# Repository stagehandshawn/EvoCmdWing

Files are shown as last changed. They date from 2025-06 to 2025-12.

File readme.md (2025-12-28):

# EvoCmdWing - [Wiki](https://github.com/stagehandshawn/EvoCmdWing/wiki)

<table width="100%">
  <tr>
    <td width="70%">
      <table width="100%">
        <tr>
          <td align="left">
            <strong>Author:</strong> ShawnR
          </td>
          <td align="right">
            <strong>Contact:</strong> <a href="mailto:stagehandshawn@gmail.com">stagehandshawn@gmail.com</a>
          </td>
        </tr>
      </table>
      <br>
      Control grandMA3 onPC with a custom keyboard with 5 attribute encoders and 8 XKey encoders synced using Midi, backlit Xkeys with on/off and color status (follows appearances).
      <br><br><blockquote>
        <strong>Note:</strong> This Guide is a work in progress but EvocmdWing is fully functional. I continue to work on the repo as time permits.
      </blockquote>
    </td>
    <td width="30%" align="right" valign="top">
      cmdwing
    </td>
  </tr>
</table>

---
## Project Images

<table>
  <tr>
    <td width="50%">
      cmdwingtop
    </td>
    <td width="50%">
      cmdwingside
    </td>
  </tr>
  <tr>
    <td width="50%">
      cmdwingback
    </td>
    <td width="50%">
      faderwingcmdwing
    </td>
  </tr>
</table>

**Watch the demo video**

Watch the demo video (https://www.youtube.com/watch?v=7ICJlkqCzxY)

## Overview
 - Sends custom keys to grandMA3 onPC when paired with `/help_files/EvoCmdWingv0.2_keyboard_shortcuts.xml` you will have a nice control surface.
 - LED feedback for XKeys with manual brightness adjustment  
   - Hold "Encoder Flip" button and Rotate Encoder 11 (logo), 12 (Sequence Off brightness), 13(Sequence On brightness)
 - 5 Relative Attribute Encoders
   - Sensitivity adjustment - Hold "Encoder Flip" button and adjust using Encoder 5 - XKeys will show level (1-8)
 - 8 Absolute XKey Encoders
   - Sensitivity adjustment - Hold "Encoder Flip" button and adjust using Encoder 6 - XKeys will show level (1-8)
 - Keyboard now uses custom keyboard firmware (better enumeration than QMK) [EvoCmdWingKeyboard](https://github.com/stagehandshawn/EvoCmdWingKeyboard) You can find the compiled firmware here
 - Designed with
   - D-Type panel mount openings for changes/additions later without reprinting (e.g., adding Art-net to DMX module, hardware midi, or LTC generator)
   - Extra stand-offs for adding prototype boards for extra design options

## Getting started
- [Bill Of Materials](https://github.com/stagehandshawn/EvoCmdWing/wiki/Bill-of-Materials)

- [Pin Assignments](https://github.com/stagehandshawn/EvoCmdWing/wiki/Pin-Assignments)

- [Wiring Diagrams](https://github.com/stagehandshawn/EvoCmdWing/wiki/Wiring-Diagrams)

## Required firmware for keyboard
- There is now a folder `./keyboard_custom_firmware` that has custom keyboard firmware for the keyboard
- I have left the QMK firmware but the custom keyboard works better with windows as I had some trouble with disconneting and reconneting the EvoCmdWing requiring a reboot for the keyboard to enumerate.
- You can also find the repo with the code to the custom keyboard here [EvoCmdWingKeyboard](https://github.com/stagehandshawn/EvoCmdWingKeyboard)

## Required Plugins
#### EvoCmdWingMidi

- Lua script `/lua/evocmdwingmidi_main.lua`
- Polls executors and sends fader value, on/on status, and color updates to EvoCmdWing using midi.  
- Tracks sequences set to the XKeys and keeps them synced between page changes and sequence moves.  
- You can set custom Encoder Press actions (toggle is default) in Midi Remotes for more control.  

  - The plugin will create required Midi Remotes automatically if they are not present.  
  - You can create them manually with the plugin and batch change the action for pressing the encoder.  
  - You can change each one seperatly in the Midi Remtoes option as well.  

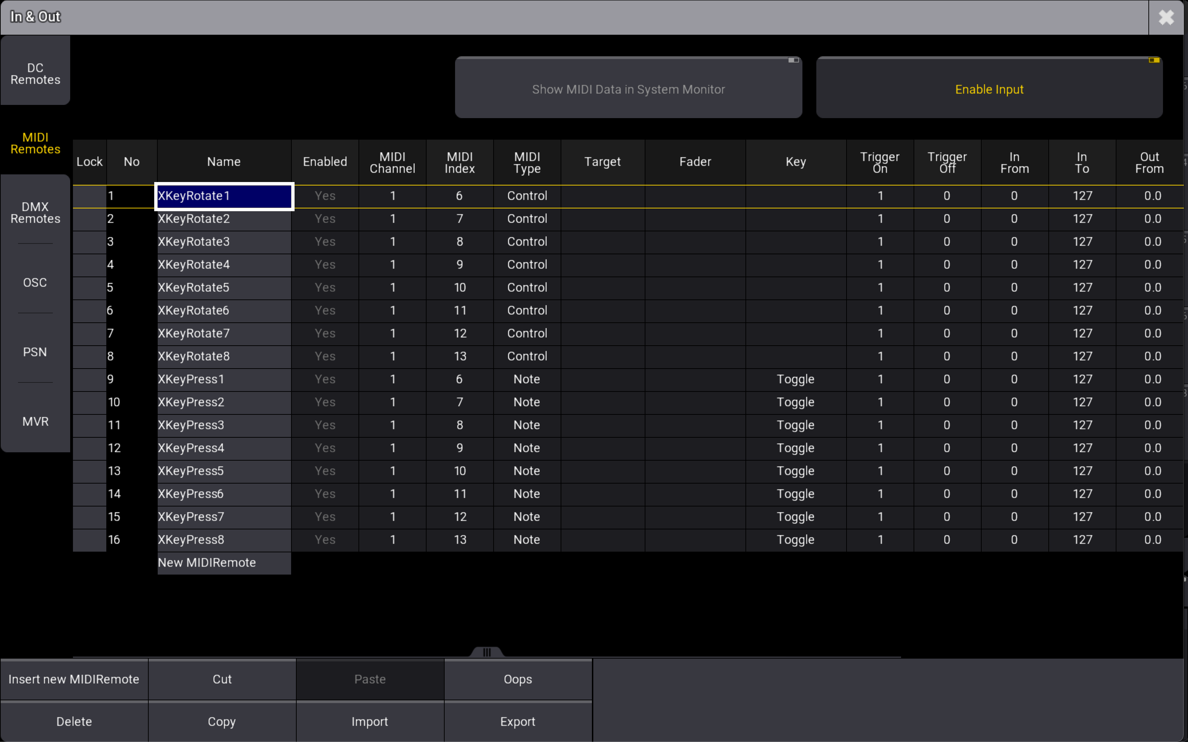
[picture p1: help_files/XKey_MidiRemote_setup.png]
midiRemotes


#### [Pro Plugins MidiEncoders](https://www.ma3-pro-plugins.com/midi-encoders)  
 - Required for taking Midi input and controlling the attribute encoders.  
 - Use Midi Standard and Relative Mode 3.  
 - The top backlit button refered to as "Encoder Flip" is used to flip from Inner/Outter encoder usage, USE NOTE 14.

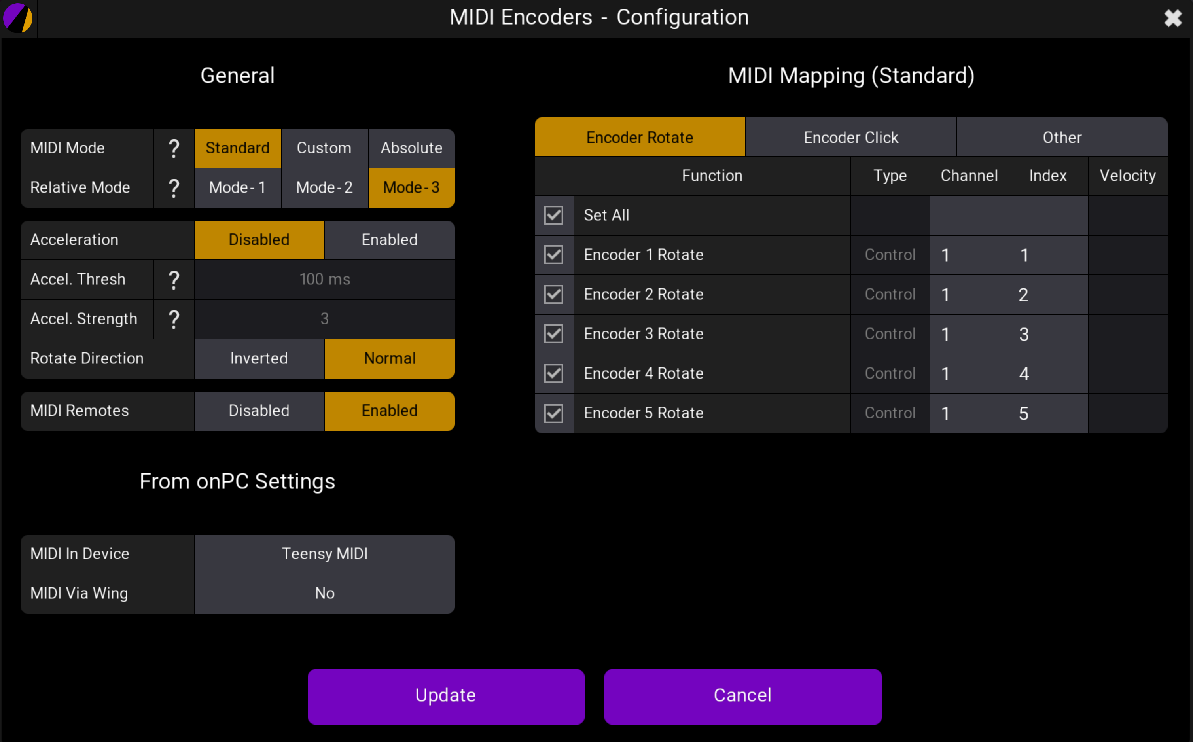
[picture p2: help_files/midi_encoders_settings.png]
midi_encoders_settings


## Full Instructions comming soon, for now...
 - Check the [Wiki](https://github.com/stagehandshawn/EvoCmdWing/wiki)  
 - The `/help_files` and `/images` folders have some helpful files.  

## Inspiration
 - Check out this project! I used it as a starting point but eventually redesigned it to be closer to the layout of a console and to have more control surfaces, and feedback.
 - https://www.thingiverse.com/thing:6464653
 - Thanks to Nathan_I3 for the inspiration for this project!

## Also check out [EvoFaderWing](https://github.com/stagehandshawn/EvoFaderWing) for a complete at home programming setup.
evocmdfaderwing
#### More to come. Thank you for checking out my project!

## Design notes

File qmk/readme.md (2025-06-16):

# These are the files needed to compile the custom keyboard for the teensy 4.0
# you will need qmk cli, you can use the keymap for a different mcu, the teensy is overkill
# there are many resources on  building custom keyboard that will help with wiring

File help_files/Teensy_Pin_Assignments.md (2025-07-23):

# Teensy 4.1 Pin Assignments - EvoCmdWing

## Overview
The EvoCmdWing uses a Teensy 4.1 mcu to manage 13 encoders with buttons, Inner/outter toggle, NeoPixel LEDs, and MIDI communication for the grandMA3.

## Encoder Pin Assignments

### Attribute Encoders (1-5)

| Encoder | Pin A | Pin B | Button Pin | MIDI Note | Function |
|---|---|---|---|---|---|
| 1 | 0 | 1 | 28 | 1 | Attribute Control |
| 2 | 2 | 3 | 29 | 2 | Attribute Control |
| 3 | 4 | 5 | 30 | 3 | Attribute Control |
| 4 | 6 | 7 | 31 | 4 | Attribute Control |
| 5 | 8 | 9 | 32 | 5 | Attribute Control |

### XKey Encoders (6-13) 
*Mapped to grandMA3 XKeys 1-8 (Executors 291-298)*

| Encoder | Pin A | Pin B | Button Pin | MIDI Note | XKey # | Executor |
|---|---|---|---|---|---|---|
| 6 | 11 | 12 | 33 | 6 | 1 | 291 |
| 7 | 14 | 15 | 34 | 7 | 2 | 292 |
| 8 | 16 | 17 | 35 | 8 | 3 | 293 |
| 9 | 18 | 19 | 36 | 9 | 4 | 294 |
| 10 | 20 | 21 | 37 | 10 | 5 | 295 |
| 11 | 22 | 23 | 38 | 11 | 6 | 296 |
| 12 | 24 | 25 | 39 | 12 | 7 | 297 |
| 13 | 26 | 27 | 40 | 13 | 8 | 298 |

## Attribute Encoder Inner/Outter Toggle

| Pin | Function | MIDI Note | Description |
|-----|---|---|---|
| 41  | Inner/Outer Toggle | 14 | Switches encoder functions between inner/outer ring |
| 13  | Latch LED || Status LED for Inner/Outer encoder mode |

**LED Indicator:**
- Pin 13 (Latch LED) shows Inner/Outer mode status
- LED ON = Outer mode active
- LED OFF = Inner mode active

## NeoPixel LED Configuration

| Pin | Function | Description |
|-----|---|---|
| 10  | NeoPixel Data | WS2812B LED strip data signal (58 total pixels) |

### Total LED Count: 58 Pixels

| LED Range | Function | Count | Description |
|---|---|---|---|
| 0-5 | Logo | 6 | Project logo illumination |
| 6-57 | XKey LEDs| 52 | Status indicators for XKeys |

### XKey LED Mapping
*Each XKey has 2 status LEDs*

| XKey | First LED | Second LED | Executor Range |
|---|---|---|---|
| 1 | 7 | 8 | 291 |
| 2 | 10 | 11 | 292 |
| 3 | 13 | 14 | 293 |
| 4 | 16 | 17 | 294 |
| 5 | 20 | 21 | 295 |
| 6 | 23 | 24 | 296 |
| 7 | 26 | 27 | 297 |
| 8 | 29 | 30 | 298 |
| 9 | 32 | 33 | 191 |
| 10 | 35 | 36 | 192 |
| 11 | 38 | 39 | 193 |
| 12 | 41 | 42 | 194 |
| 13 | 45 | 46 | 195 |
| 14 | 48 | 49 | 196 |
| 15 | 51 | 52 | 197 |
| 16 | 54 | 55 | 198 |

**Note:** Pixels 9, 12, 15, 18, 19, 22, 25, 28, 31, 34, 37, 40, 43, 44, 47, 50, 53, 56 are used as spacers/gaps between XKey groups.

## MIDI Configuration

| Channel | Direction | Purpose | CC/Note Range |
|---|---|---|---|
| 1 | Output | Encoder values and button presses | CC 6-13, Notes 1-14 |
| 2 | Input | XKey status and RGB data | CC 1-64 |
| 3 | Input | Page change notifications | CC 1 |

### MIDI Mapping Details

**Outgoing (Channel 1):**
- Encoders 6-13: Send CC 6-13 (fader values)
- All buttons: Send Note On/Off 1-14

**Incoming (Channel 2):**
- XKey Status: CC 1-16 (0=empty, 65=off, 127=on)
- XKey RGB: CC 17-64 (3 CCs per XKey for R,G,B values)

**Incoming (Channel 3):**
- Page Changes: CC 1 (page number 1-127)

## Special Modes

### Brightness Adjustment Mode
**Activation:** Hold button 14 (pin 41)

| Encoder | Function | Range |
|---|---|---|
| 12 | Off-state brightness | 0-255 |
| 13 | On-state brightness | 0-255 |

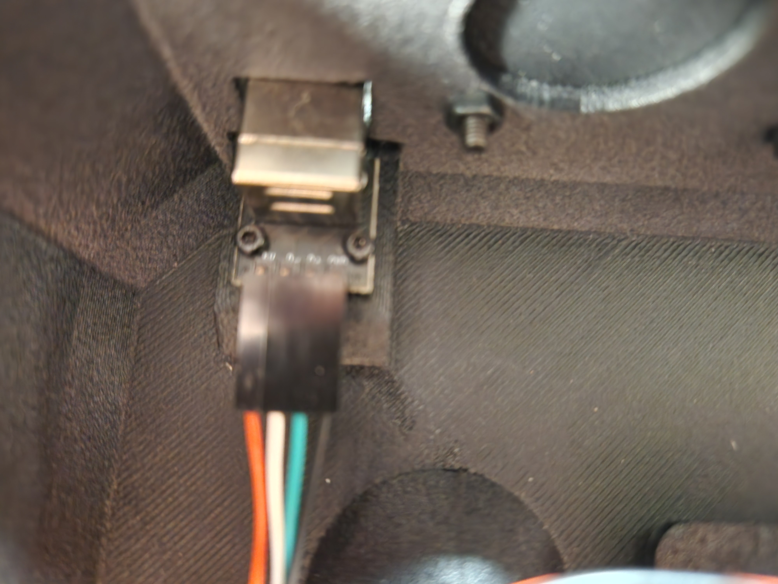
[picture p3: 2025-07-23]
images/usb_b_connector.jpg

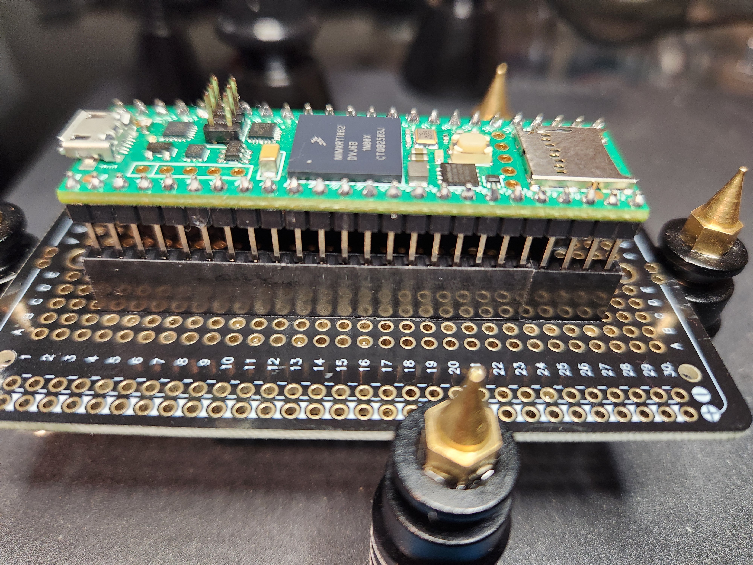
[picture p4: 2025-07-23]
images/teensy_4.1_board_0.jpg

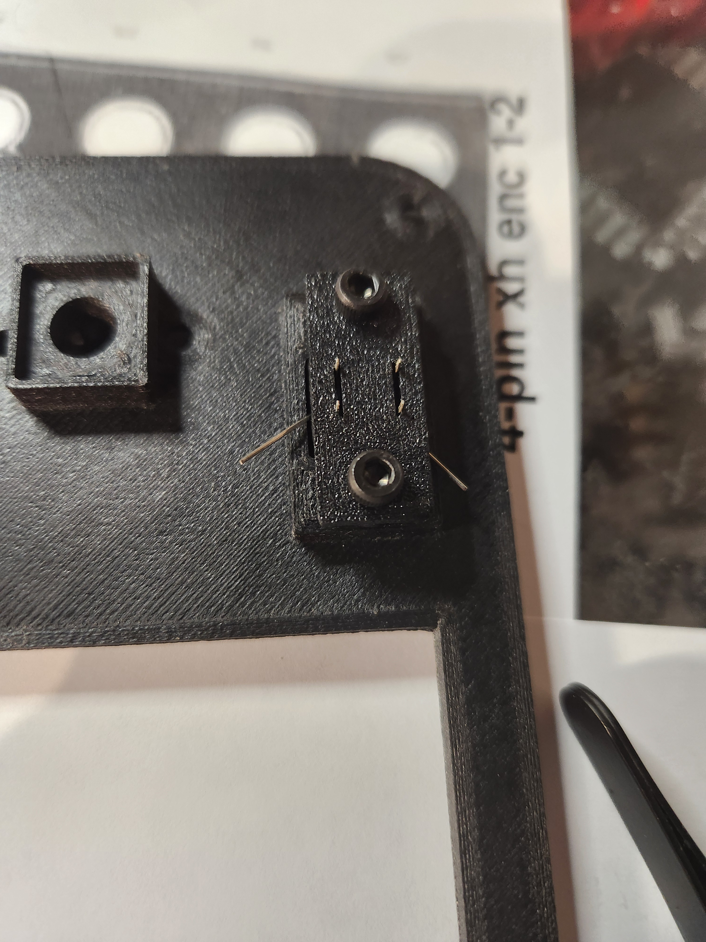
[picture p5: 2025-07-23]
images/encoder_flip_button_bottom.jpg

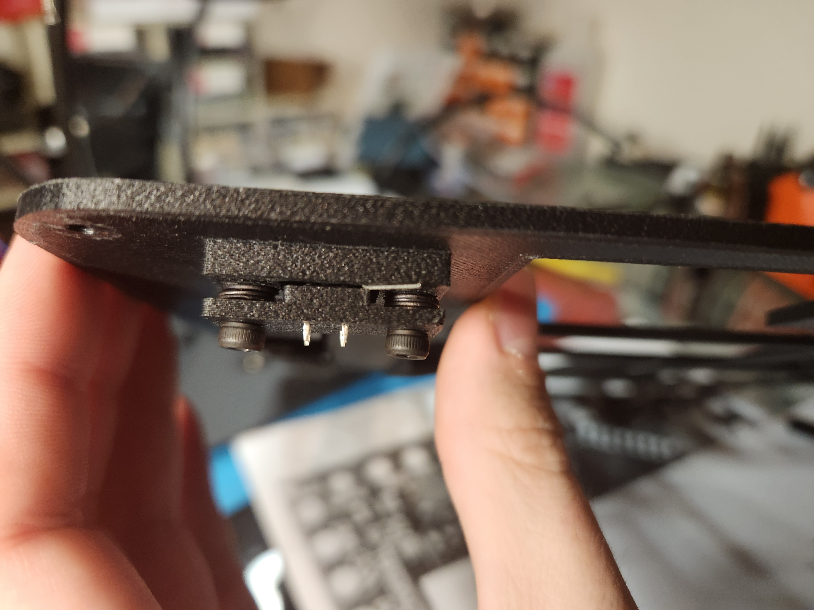
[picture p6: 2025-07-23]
images/encoder_flip_button_side.jpg

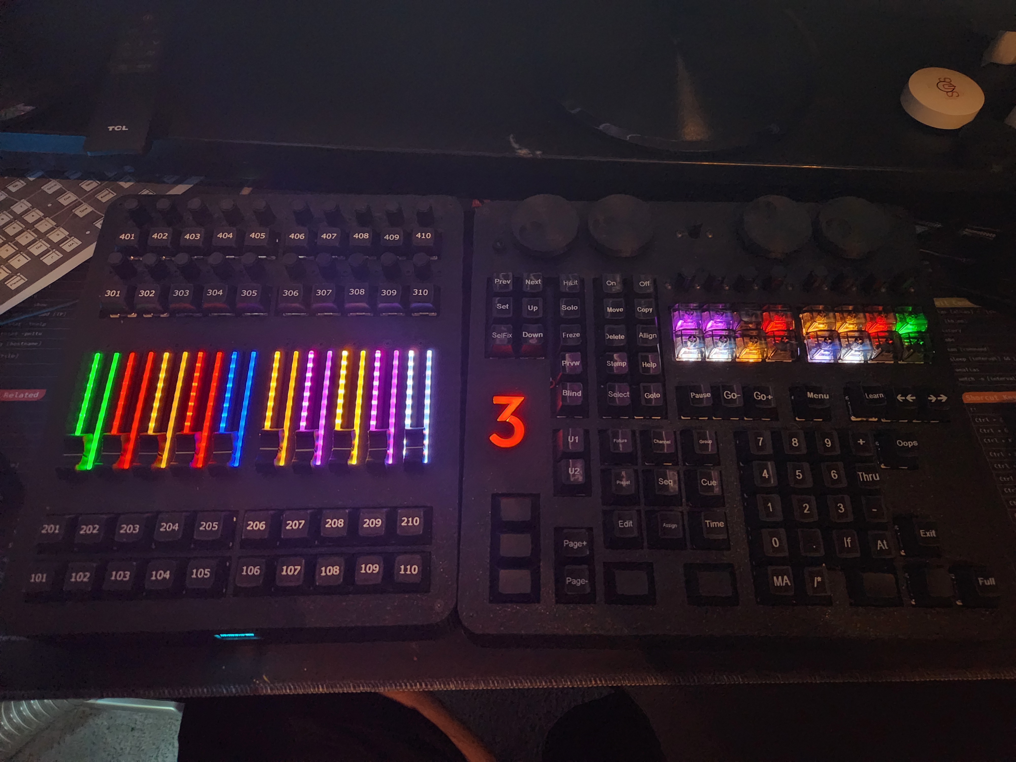
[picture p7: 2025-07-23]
images/evocmdwingv0.2.jpeg

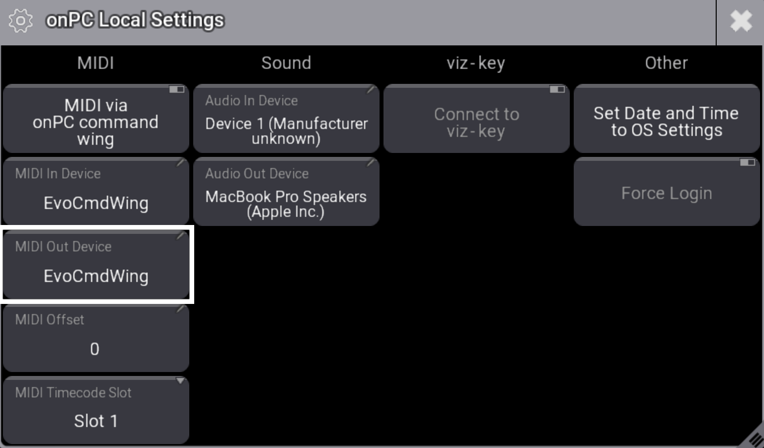
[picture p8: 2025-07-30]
help_files/onPC_midi_settings.png

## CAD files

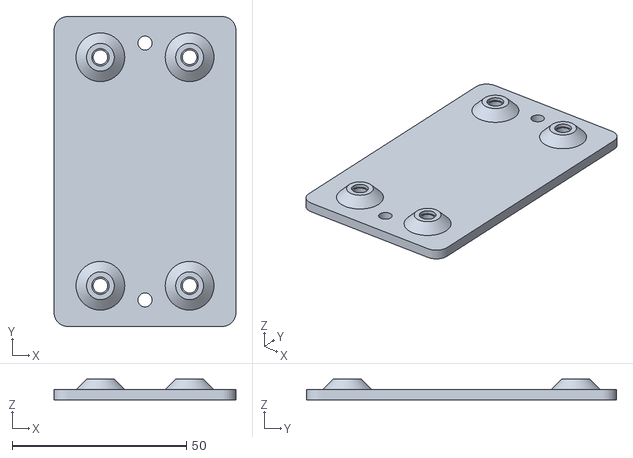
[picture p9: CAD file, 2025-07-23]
Cad_models/V0.2/stls/board_mounts/70X30mm_board_mount.stl
52.2 x 89.0 x 6.00

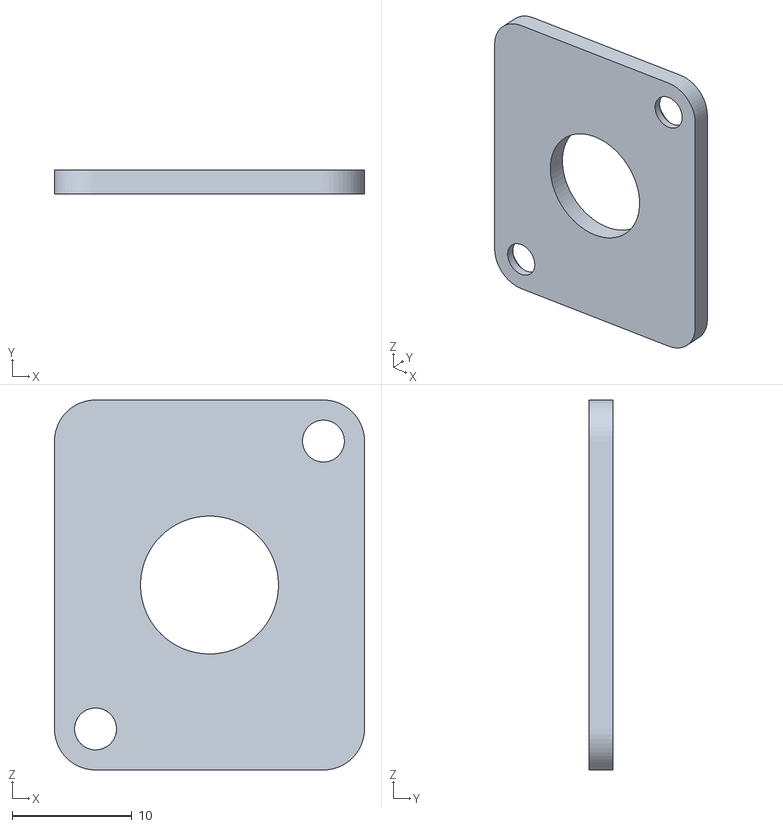
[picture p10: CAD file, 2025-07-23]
Cad_models/V0.2/stls/D-type_DC_barrel_plate.stl
25.8 x 2.00 x 30.8

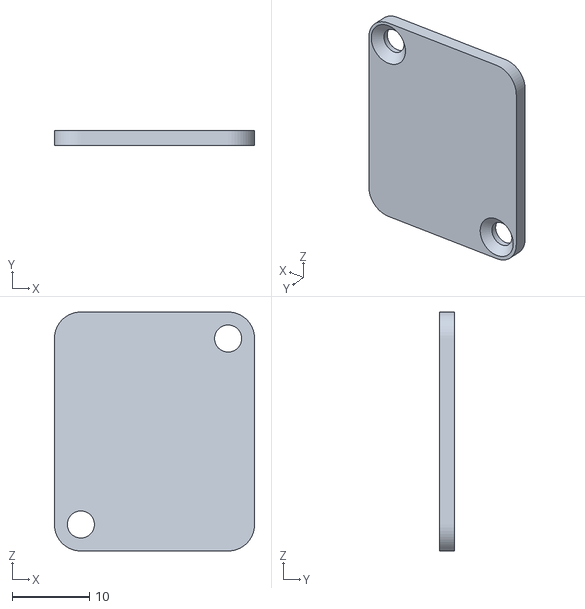
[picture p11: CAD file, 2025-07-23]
Cad_models/V0.2/stls/Blank D-type.stl
25.8 x 2.00 x 30.8

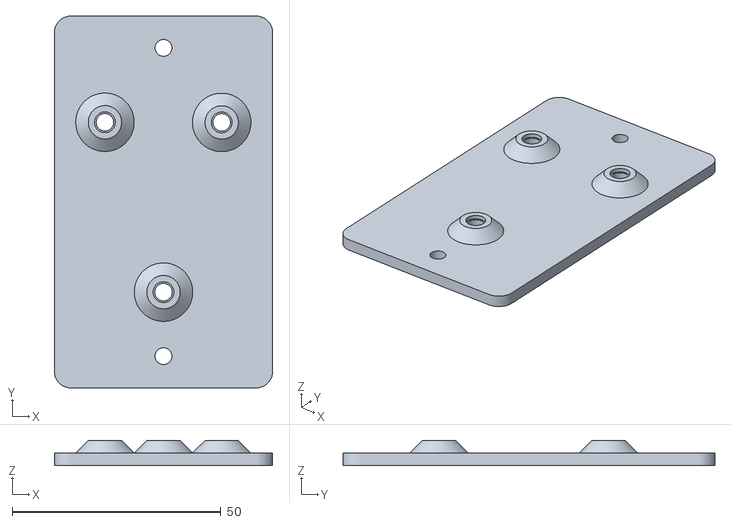
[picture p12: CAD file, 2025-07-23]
Cad_models/V0.2/stls/board_mounts/teensy4.0_breakout_mount.stl
52.2 x 89.0 x 6.00

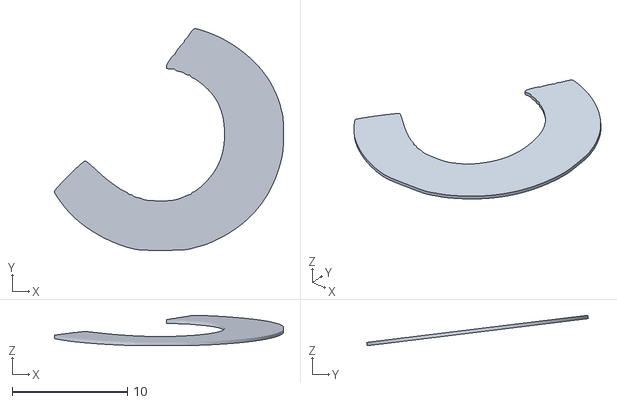
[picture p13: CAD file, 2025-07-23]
Cad_models/V0.2/stls/Logo_3_bottom.stl
19.9 x 19.2 x 2.64

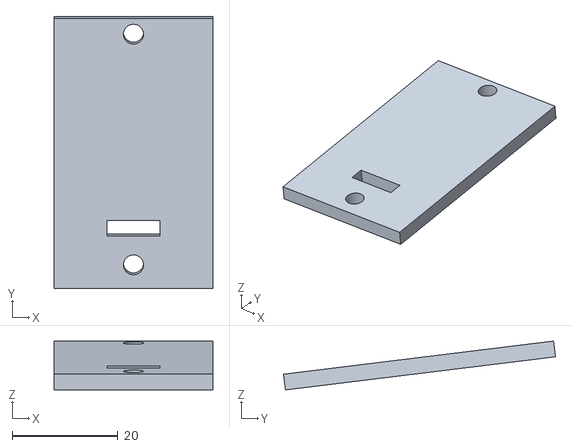
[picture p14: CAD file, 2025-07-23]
Cad_models/V0.2/stls/logo_led_holder.stl
30.0 x 51.5 x 9.25

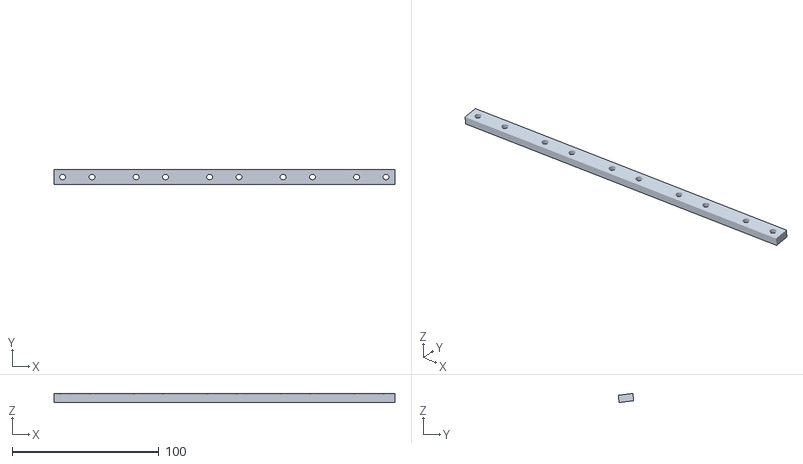
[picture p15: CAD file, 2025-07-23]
Cad_models/V0.2/stls/big encoder mount.stl
232.0 x 10.5 x 6.18

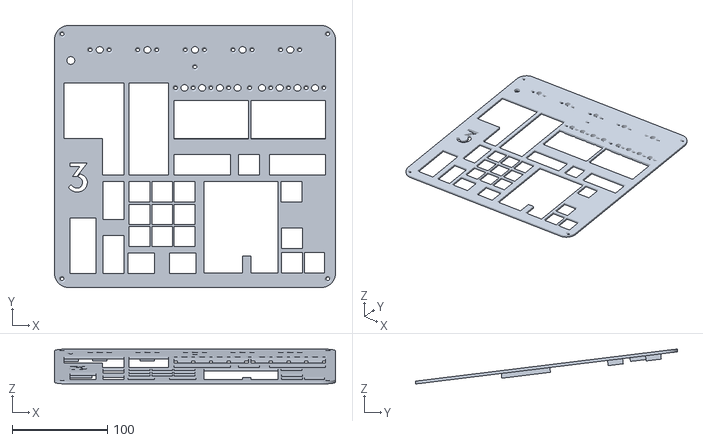
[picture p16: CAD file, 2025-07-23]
Cad_models/V0.2/stls/Top.stl
295.0 x 275.3 x 36.7

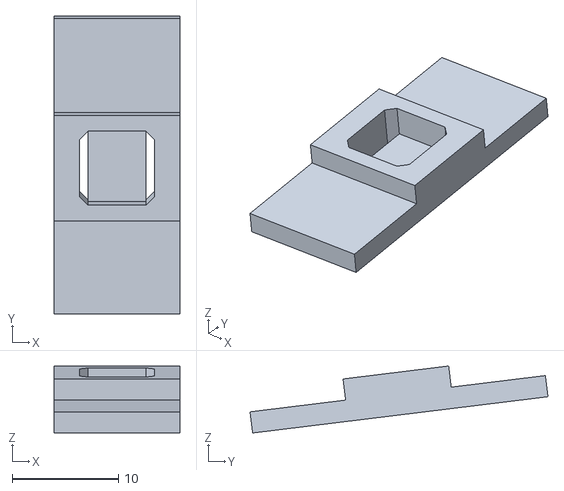
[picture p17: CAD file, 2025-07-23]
Cad_models/V0.2/stls/encoder_flip_button_body.stl
11.8 x 28.0 x 6.29

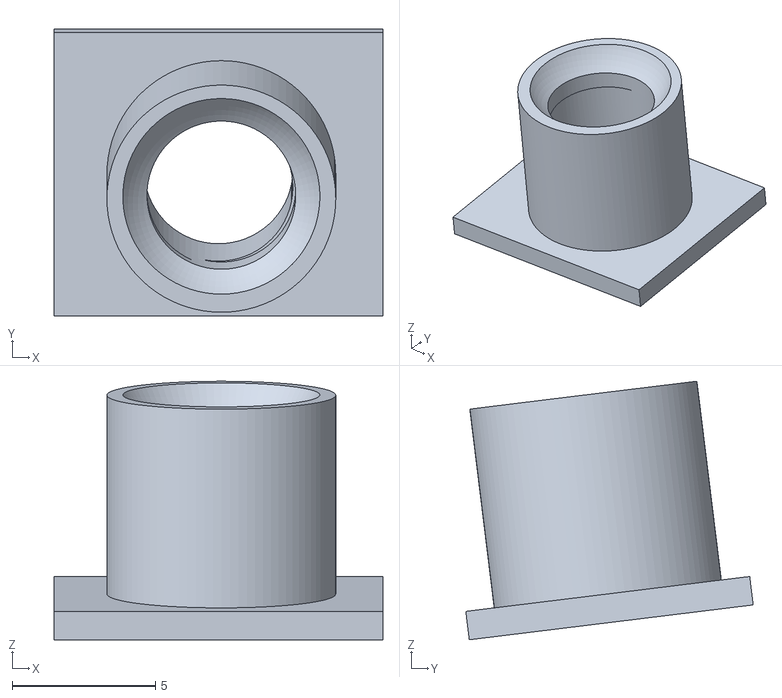
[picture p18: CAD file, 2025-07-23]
Cad_models/V0.2/stls/encoder_flip_button_5mmLED.stl
11.5 x 10.0 x 9.04

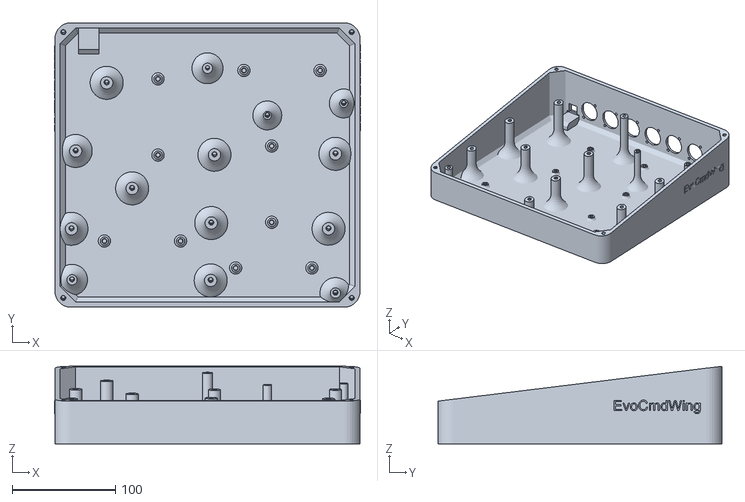
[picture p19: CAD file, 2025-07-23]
Cad_models/V0.2/stls/Base.stl
296.0 x 275.0 x 75.0

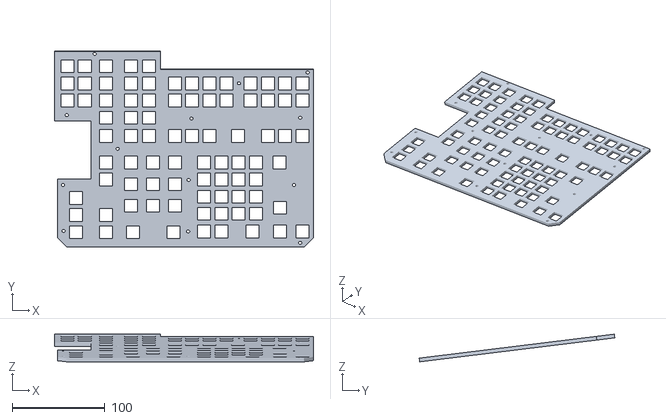
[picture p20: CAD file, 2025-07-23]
Cad_models/V0.2/stls/Keyplate.stl
278.9 x 210.7 x 29.8

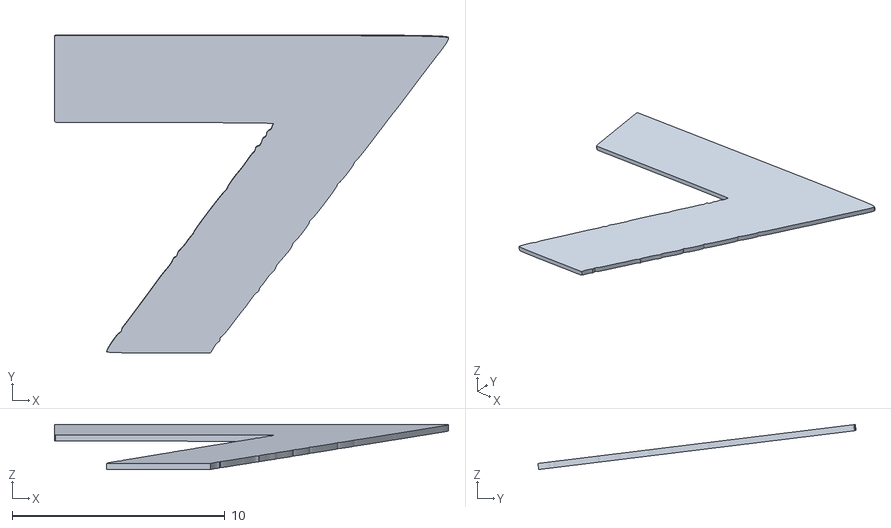
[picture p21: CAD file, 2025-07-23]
Cad_models/V0.2/stls/Logo_3_top.stl
18.5 x 15.0 x 2.12

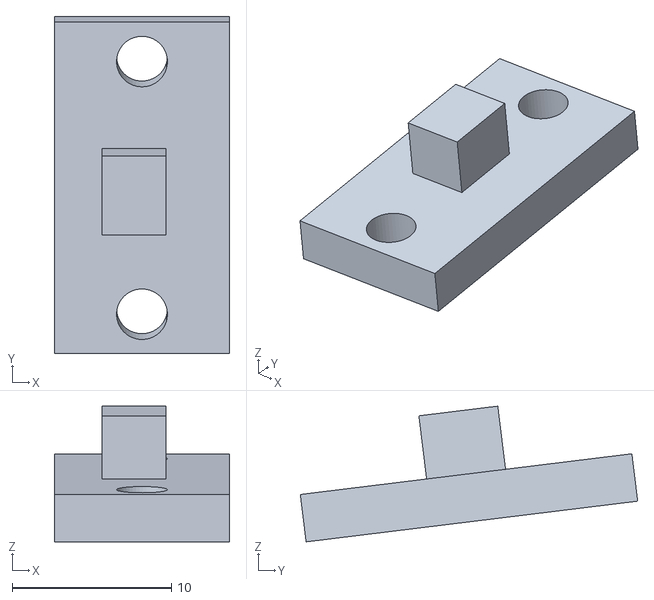
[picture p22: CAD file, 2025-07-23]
Cad_models/V0.2/stls/button_mount.stl
11.0 x 21.2 x 8.53

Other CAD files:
Cad_models/V0.2/stls/small_encoder_mount.stl
Cad_models/V0.2/stls/encoder_flip_button_soild_no_led.stl
Cad_models/V0.2/stls/encoder_wheel.stl
Cad_models/V0.1/stls/Keyplate.stl
Cad_models/V0.1/gma3cmdwingV1.f3d
Cad_models/V0.1/stls/Base.stl
Cad_models/V0.1/stls/Top.stl
Cad_models/V0.1/stls/big encoder mount.stl
Cad_models/V0.1/stls/encoder_spacer.stl
Cad_models/V0.1/stls/encoder_wheel.stl
Cad_models/V0.1/stls/small encoder mount.stl
Cad_models/V0.1/stls/stand_tilted.stl

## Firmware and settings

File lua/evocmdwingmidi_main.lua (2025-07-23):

-- EvoCmdWingMidi v0.2
-- This lua script will poll midi remotes in grandma3 for the name XKeyRotate1-8 and XKeyPress1-8
-- XKeyRotate remotes handle fader control from encoders with MIDI feedback of current fader value
-- XKeyPress remotes target the same sequences but allow manual key configuration (press for toggle/on/off etc..)

-- MIDI Remotes:
--     Main loop will auto create the following MIDI Remotes when not present
--         XKeyRotate1-8: channel 1 cc 6-13 (fader control with feedback)
--         XKeyPress1-8: channel 1 note 6-13 (key presses, manual configuration)
--    The defualt function of pressing an Encoder (XKeyPress1-8) is Toggle, you can manually change each or use the Create Midi Remotes button to batch change them

-- The script will:
--     Update the MidiRemote Targets with the current sequences assigned to the XKeys to keep track of pages changes and moving of sequences
--     Track and send the fader values for Executors 291-298 for syncing encoder values for XKeys 1-8
--     Track and send the status of Executors 191-198 and 291-298 (XKeys 1-16) Tracks: Populated/On/Off/Appearance Color
--     Cache status data to reduce midi traffic on page changes and will send updates when assignments or appearance changes

-- Midi Channels:
--     Channel 1: Fader sync: XKeys 1-8 use CC 6-13 (only on sequence changes/page changes) Manually chaning XKey Encoder values in software will cause Physical Encoders to be out of sync until page/sequence change
--     Channel 2: Status: XKeys 1-16 use CC 1-16 (populated/on/off state)
--     Channel 2: RGB: XKeys 1-16 use CC 17-64 (3 CCs each (rgb), only sent when populated and not black)
--     Channel 3: Page changes: CC 1 = current page number (1-127)

-- Status encoding:
--     Status encoding: 0=not populated, 65=populated+off, 127=populated+on
--     RGB: 0-127 per rgb channel, black sequences sent as white (127,127,127) for visibility
--         You can change the default color variables to replace black appearances
--     Page tracking: Caches state for pages, only sends changes
--     Fader sync: Only sends fader values when sequence assignments change (prevents encoder jumping)

-- XKey RGB
--     You can change the defualt color of newly created XKeys below, it replaces black (can be black for default LEDs off)

-- Many thanks to LenschCode for the original code from Midi Executors v1.1.0
-- GNU GPLv3

local loop
-- Refreshrate in seconds, I spent a lot of time getting the script to be as effecient as possible beause we are using polling, 100ms seems to work great
local rate = 0.1         --100ms

-- Starting CC for MIDI feedback
local startingCC = 6
-- local endingCC = startingCC + 7  -- CC 6-13 for XKeys 1-8
local midiChannel = 1
local statusMidiChannel = 2
local pageMidiChannel = 3

-- Default color for black (0,0,0) sequences - for visibility
local defaultRed = 255
local defaultGreen = 255
local defaultBlue = 255

local running = false
local debugMode = false -- Debug output mode - off by default
local currentPage = nil -- Track current page

-- Page-based state tracking for up to 127 pages
local pageIndex = {} -- Track which pages we've indexed: pageIndex[pageNum] = true
local pageExecutorStates = {} -- [pageNum][execNum] = {populated, on, colorR, colorG, colorB}
local startupComplete = false -- Track if we've done initial indexing

-- Change tracking for exeecutors
local changedExecutors = {} -- List of executors that changed on current page

-- MIDI Remote caching
local cachedXKeyRemotes = {} -- Cache of found XKey remotes: {remote_object, exec_info}
local remoteCacheComplete = false -- Track if we've cached all remotes
local expectedRemoteCount = 16 -- XKeyRotate1-8 + XKeyPress1-8

-- All Executors (Xkeys) to monitor
local EXECUTORS_TO_MONITOR = {191,192,193,194,195,196,197,198,291,292,293,294,295,296,297,298}

-- Current page
local currentCyclePageNum = nil

-- Debug print function - only prints if debug mode is enabled
local function DebugPrint(...)
    if debugMode then
        Printf(...)
    end
end


-- Clear all cached state variables (called on script startup)
local function clearAllCachedState()
    currentPage = nil
    pageIndex = {}
    pageExecutorStates = {}
    startupComplete = false
    changedExecutors = {}
    
    -- Clear MIDI remote cache
    cachedXKeyRemotes = {}
    remoteCacheComplete = false
    
    -- Clear page cache
    currentCyclePageNum = nil
    
    DebugPrint("Cached state cleared - ready for direct access sync")
end


local function getDirectExecutorInfo(execNum)
    -- Get executor status
    local exec, page = GetExecutor(execNum)
    
    if not exec then
        -- Executor doesn't exist
        return {
            faderValue = 0,
            isOn = false,
            isPopulated = false,
            color = {r = 0, g = 0, b = 0},
            object = nil,
            faderRef = nil
        }
    end
    
    -- Get all live values directly from the executor
    local faderValue = exec:GetFader{token = "FaderMaster", faderDisabled = false} or 0
    local myObject = exec.Object
    local isPopulated = (myObject ~= nil)
    local isOn = isPopulated and myObject:HasActivePlayback() or false
    
    -- Get color data
    local color = {r = 0, g = 0, b = 0}
    if isPopulated then
        local apper = myObject["APPEARANCE"]
        if apper then
            color = {
                r = apper['BACKR'] or 0,
                g = apper['BACKG'] or 0,
                b = apper['BACKB'] or 0
            }
        end
    end
    
    -- Get fader reference for MIDI remote assignment
    local faderRef = nil
    local objectListExec = ObjectList("page " .. currentCyclePageNum .. "." .. execNum)[1]
    if objectListExec then
        faderRef = objectListExec.fader
    end
    
    return {
        faderValue = faderValue,
        isOn = isOn,
        isPopulated = isPopulated,
        color = color,
        object = myObject,
        faderRef = faderRef
    }
end


local function getXKeyMapping(remoteName)
    -- Handle both XKeyRotate and XKeyPress remotes
    local rotateNum = remoteName:match("^[Xx][Kk]ey[Rr]otate(%d+)$")
    local pressNum = remoteName:match("^[Xx][Kk]ey[Pp]ress(%d+)$")
    
    local executorNumber = nil
    local remoteType = nil
    
    local keyNum = nil
    if rotateNum then
        keyNum = tonumber(rotateNum)
        executorNumber = 290 + keyNum -- XKeyRotate1 = 291, etc.
        remoteType = "Fader"
    elseif pressNum then
        keyNum = tonumber(pressNum)
        executorNumber = 290 + keyNum -- XKeyPress1 = 291, etc.
        remoteType = "Key"
    end
    
    if executorNumber and (executorNumber >= 291 and executorNumber <= 298) then
        return {
            page = currentCyclePageNum,
            id = executorNumber,
            type = remoteType,
            xkeyNum = keyNum
        }
    else
        return nil
    end
end


local function sendMidiFeedback(ccNumber, value)
    local midiValue = math.floor((value / 100) * 127)
    local command = 'SendMIDI "Control" ' .. midiChannel .. '/' .. ccNumber .. ' ' .. midiValue
    Cmd(command)
    
    coroutine.yield(0.010) -- 10ms delay between midi sends  to not overwhelm teensy buffer
end


local function sendMidiStatus(channel, ccNumber, value)
    local midiValue = value > 127 and 127 or (value < 0 and 0 or math.floor(value))
    local command = 'SendMIDI "Control" ' .. channel .. '/' .. ccNumber .. ' ' .. midiValue
    Cmd(command)
    coroutine.yield(0.010) -- 10ms delay
end

local function sendPageChange(pageNumber)
    local pageValue = pageNumber > 127 and 127 or (pageNumber < 1 and 1 or math.floor(pageNumber))
    sendMidiStatus(pageMidiChannel, 1, pageValue)
    DebugPrint("Page change sent: %d", pageValue)
end


local function sendMidiColor(channel, ccBase, color)
    -- Convert 0-255 color values to 0-127 MIDI values
    local rMidi, gMidi, bMidi
    
    if color.r == 0 and color.g == 0 and color.b == 0 then
        -- If color is black (0,0,0), use default color for visibility
        rMidi = math.floor((defaultRed / 255) * 127)
        gMidi = math.floor((defaultGreen / 255) * 127)
        bMidi = math.floor((defaultBlue / 255) * 127)
    else
        rMidi = math.floor((color.r / 255) * 127)
        gMidi = math.floor((color.g / 255) * 127)
        bMidi = math.floor((color.b / 255) * 127)
    end
    
    sendMidiStatus(channel, ccBase, rMidi)     -- Red
    sendMidiStatus(channel, ccBase + 1, gMidi) -- Green
    sendMidiStatus(channel, ccBase + 2, bMidi) -- Blue
end

-- Get cached executor state for comparison
local function getCachedExecutorState(pageNum, execNum)
    if not pageExecutorStates[pageNum] then
        return nil, nil, nil, nil, nil -- No cached data for this page
    end
    
    local cached = pageExecutorStates[pageNum][execNum]
    if not cached then
        return nil, nil, nil, nil, nil -- No cached data for this executor
    end
    
    return cached.populated, cached.on, cached.colorR, cached.colorG, cached.colorB
end

-- Cache executor state for future comparison
local function setCachedExecutorState(pageNum, execNum, populated, on, colorR, colorG, colorB)
    if not pageExecutorStates[pageNum] then
        pageExecutorStates[pageNum] = {}
    end
    
    pageExecutorStates[pageNum][execNum] = {
        populated = populated,
        on = on,
        colorR = colorR,
        colorG = colorG,
        colorB = colorB,
    }
end

-- Send fader sync for a specific executor (only when sequence assignment changes)
local function sendFaderSync(execNum, xkeyNum, reason)
    local currentPageNum = currentCyclePageNum
    
    -- Only send fader sync for executors 291-298 (XKeys 1-8) (Encoders 6-13)
    if execNum < 291 or execNum > 298 then
        return false
    end
    
    
    -- Get current fader value to sync Teensy encoder tracking
    local currentValue = getDirectExecutorInfo(execNum).faderValue
    local faderCCNumber = startingCC + xkeyNum - 1
    sendMidiFeedback(faderCCNumber, currentValue)
    
    DebugPrint("Executor %d (XKey %d): Fader sync=%d%% (CC:%d) - %s", 
           execNum, xkeyNum, math.floor(currentValue), faderCCNumber, reason)
    
    -- Preserve cached state (no fader state tracking needed)
    local cachedPopulated, cachedOn, cachedColorR, cachedColorG, cachedColorB = getCachedExecutorState(currentPageNum, execNum)
    setCachedExecutorState(currentPageNum, execNum, cachedPopulated, cachedOn, cachedColorR, cachedColorG, cachedColorB)
    
    return true
end

-- Send MIDI status for a specific executor 
local function sendExecutorStatus(execNum, xkeyNum, force)
    local currentPageNum = currentCyclePageNum
    
    -- Get current states
    local execInfo = getDirectExecutorInfo(execNum)
    local isPopulated = execInfo.isPopulated
    local isOn = execInfo.isOn  
    local color = execInfo.color
    
    local populatedState = isPopulated
    local onState = isOn
    local colorR, colorG, colorB = color.r, color.g, color.b
    
    -- Get cached state for comparison
    local cachedPopulated, cachedOn, cachedColorR, cachedColorG, cachedColorB = getCachedExecutorState(currentPageNum, execNum)
    
    local messagesSent = 0
    local statusChanged = force or (cachedPopulated ~= populatedState) or (cachedOn ~= onState)
    local colorChanged = force or (cachedColorR ~= colorR) or (cachedColorG ~= colorG) or (cachedColorB ~= colorB)
    local sequenceChanged = false
    
    -- Check if sequence assignment changed (for fader sync)
    local wasPopulated = cachedPopulated or false
    local becamePopulated = false
    if statusChanged and execNum >= 291 and execNum <= 298 then
        -- For executors 291-298, check if the populated state changed (sequence assignment)
        if wasPopulated ~= populatedState then
            sequenceChanged = true
            if not wasPopulated and populatedState then
                becamePopulated = true
            end
        end
    else
        -- For executors 191-198 (XKeys 9-16), check if became populated (hard-coded, no MIDI remote management)
        if not wasPopulated and populatedState then
            becamePopulated = true
        end
    end
    
    -- Send status CC only if status changed
    if statusChanged then
        local statusValue = 0
        if isPopulated then
            if isOn then
                statusValue = 127  -- Populated and on
            else
                statusValue = 65   -- Populated and off
            end
        else
            statusValue = 0  -- Not populated
        end
        
        sendMidiStatus(statusMidiChannel, xkeyNum, statusValue)
        messagesSent = messagesSent + 1
        
        DebugPrint("Executor %d (XKey %d): Status=%d (Pop=%s On=%s)", 
               execNum, xkeyNum, statusValue,
               isPopulated and "YES" or "NO", isOn and "YES" or "NO")
        
        -- Send fader sync if sequence assignment changed
        if sequenceChanged then
            sendFaderSync(execNum, xkeyNum, "sequence assignment changed")
        end
    end
    
    -- Send RGB if Key is populated AND color changed, OR Key just became populated (force RGB send for new sequences)
    if isPopulated and (colorChanged or becamePopulated) then
        local rgbCCBase = 16 + (xkeyNum - 1) * 3 + 1
        sendMidiColor(statusMidiChannel, rgbCCBase, color)
        messagesSent = messagesSent + 3
        
        if becamePopulated then
            DebugPrint("Executor %d (XKey %d): RGB=(%d,%d,%d) - newly populated", 
                   execNum, xkeyNum, color.r, color.g, color.b)
        else
            DebugPrint("Executor %d (XKey %d): RGB=(%d,%d,%d)", 
                   execNum, xkeyNum, color.r, color.g, color.b)
        end
    elseif not isPopulated and colorChanged then
        DebugPrint("Executor %d (XKey %d): Unpopulated (no RGB sent)", execNum, xkeyNum)
    end
    
    -- Update cached state if anything was sent or changed
    if statusChanged or colorChanged then
        setCachedExecutorState(currentPageNum, execNum, populatedState, onState, colorR, colorG, colorB)
    end
    
    return messagesSent > 0 -- Indicate if we sent anything
end

-- Send full page data (startup or new page indexing)
local function sendFullPageData(pageNum, reason)
    DebugPrint("=== SENDING FULL PAGE DATA: Page %d (%s) ===", pageNum, reason)
    local messagesSent = 0
    
    -- Send fader sync for executors 291-298 to initialize Teensy encoder tracking
    for execNum = 291, 298 do
        local xkeyNum = execNum - 290  -- 1-8
        if sendFaderSync(execNum, xkeyNum, reason) then
            messagesSent = messagesSent + 1
        end
    end
    
    -- Send status data for all 16
    for _, execNum in ipairs(EXECUTORS_TO_MONITOR) do
        if execNum >= 291 and execNum <= 298 then
            -- Executors 291-298 = XKeys 1-8
            local xkeyNum = execNum - 290
            if sendExecutorStatus(execNum, xkeyNum, true) then
                messagesSent = messagesSent + 1
            end
        elseif execNum >= 191 and execNum <= 198 then
            -- Executors 191-198 = XKeys 9-16  
            local xkeyNum = execNum - 190
            local actualXkeyNum = xkeyNum + 8
            if sendExecutorStatus(execNum, actualXkeyNum, true) then
                messagesSent = messagesSent + 1
            end
        end
    end
    
    -- Mark page as indexed
    pageIndex[pageNum] = true
    
    DebugPrint("Full page data sent: %d messages", messagesSent)
end

-- Send changes for current page
local function sendChangedExecutors()
    local messagesSent = 0
    
    local changedExecCount = 0
    for _ in pairs(changedExecutors) do 
        changedExecCount = changedExecCount + 1 
    end
    
    DebugPrint("=== PROCESSING CHANGES ===\nChanged executors: %d", changedExecCount)
    
    -- Process all changed executors immediately
    for execNum, _ in pairs(changedExecutors) do
        if execNum >= 291 and execNum <= 298 then
            -- Executors 291-298 = XKeys 1-8
            local xkeyNum = execNum - 290  -- 1-8
            
            -- Send status data (includes fader sync if sequence changed)
            if sendExecutorStatus(execNum, xkeyNum, false) then
                messagesSent = messagesSent + 1
                DebugPrint("Executor %d (XKey %d) status updated", execNum, xkeyNum)
            end
            
        elseif execNum >= 191 and execNum <= 198 then
            -- Executors 191-198 = XKeys 9-16
            local xkeyNum = execNum - 190  -- 1-8
            local actualXkeyNum = xkeyNum + 8  -- 9-16
            
            if sendExecutorStatus(execNum, actualXkeyNum, false) then
                messagesSent = messagesSent + 1
                DebugPrint("Executor %d (XKey %d) status updated", execNum, actualXkeyNum)
            end
        end
    end
    
    -- Clear changed executors list after processing
    changedExecutors = {}
    
    DebugPrint("Messages sent: %d", messagesSent)
end

local function checkForExecutorChanges()
    local currentPageNum = currentCyclePageNum
    local contentChanged = false
    local stateChanged = false
    local colorChanged = false
    local pageChanged = false
    
    -- Check if page changed
    if currentPage == nil then
        -- First startup
        currentPage = currentPageNum
        pageChanged = true
        
        if not startupComplete then
            DebugPrint("=== STARTUP: Indexing page %d ===", currentPageNum)
            sendPageChange(currentPageNum)
            sendFullPageData(currentPageNum, "startup")
            startupComplete = true
            return -- Exit early after startup
        end
        
    elseif currentPage ~= currentPageNum then
        -- Page actually changed
        DebugPrint("=== PAGE CHANGE: %d → %d ===", currentPage, currentPageNum)
        currentPage = currentPageNum
        pageChanged = true
        
        -- Send page change notification
        sendPageChange(currentPageNum)
        
        -- Check if this page has been indexed before
        if not pageIndex[currentPageNum] then
            -- New page - send full data including fader sync
            DebugPrint("New page detected - sending full data")
            sendFullPageData(currentPageNum, "new page")
            return -- Exit early after full page send
        else
            -- Known page - send fader sync for encoder tracking, then let normal change detection handle differences
            DebugPrint("Returning to known page %d - sending fader sync", currentPageNum)
            for execNum = 291, 298 do
                local xkeyNum = execNum - 290  -- 1-8
                sendFaderSync(execNum, xkeyNum, "known page change")
            end
        end
    end
    
    -- Check for executor state changes
    for _, execNum in ipairs(EXECUTORS_TO_MONITOR) do

            local execInfo = getDirectExecutorInfo(execNum)
            local currentObject = execInfo.object
            local isPopulated = execInfo.isPopulated
            local currentOnState = execInfo.isOn
            local currentColor = execInfo.color
            
            -- Get cached state for comparison 
            local cachedPopulated, cachedOn, cachedColorR, cachedColorG, cachedColorB = getCachedExecutorState(currentPageNum, execNum)
            
            local executorChanged = false
            
            -- Check if status changed from cached state
            if (cachedPopulated ~= isPopulated) or (cachedOn ~= currentOnState) then
                DebugPrint("[CHANGE] Executor %d: Status changed (Populated: %s, On: %s)", 
                       execNum, isPopulated and "true" or "false", currentOnState and "true" or "false")
                executorChanged = true
                contentChanged = true
                stateChanged = true
            end
            
            -- Check if color changed from cached state
            if (cachedColorR ~= currentColor.r) or (cachedColorG ~= currentColor.g) or (cachedColorB ~= currentColor.b) then
                DebugPrint("[CHANGE] Executor %d: Color changed to RGB(%d,%d,%d)", 
                       execNum, currentColor.r, currentColor.g, currentColor.b)
                executorChanged = true
                colorChanged = true
            end
            
            -- Mark executor as changed if any property changed
            if executorChanged then
                changedExecutors[execNum] = true
            end
    end
    
    -- Send feedback if anything changed (but not for page changes - handled above)
    if not pageChanged and (contentChanged or stateChanged or colorChanged) then
        if contentChanged then
            DebugPrint("=== Executor content changes detected ===")
        end
        if stateChanged then
            DebugPrint("=== Executor state changes detected ===")
        end
        if colorChanged then
            DebugPrint("=== Executor color changes detected ===")
        end
        
        -- Small delay for grandMA to finish processing the changes
        coroutine.yield(0.1) -- 100ms delay
        
        DebugPrint("=== Sending MIDI updates ===")
        sendChangedExecutors()
    end
end


-- MIDI REMOTE CREATION --
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

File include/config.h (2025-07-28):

#ifndef CONFIG_H
#define CONFIG_H

#include <Arduino.h>
#include <Adafruit_NeoPixel.h>
#include <Encoder.h>
#include "eepromStorage.h"

typedef unsigned char byte;

// ================================
// PROJECT INFORMATION
// ================================
const char* const PROJECT_VERSION = "0.2";
const char* const PROJECT_NAME = "EvoCmdWing";

// ================================
// PIN DEFINITIONS
// ================================
const int LED_PIN = 10;              // NeoPixel data pin
const int LATCH_LED_PIN = 13;        // GPIO pin for latching inner outter flip button

// ================================
// ENCODER/BUTTON CONFIGURATION
// ================================
const int N_ENCODERS = 13;
const int N_BUTTONS = 14;

// GPIO pins for encoder a/b
extern const int ENC_PINS[N_ENCODERS][2];

// GPIO pin for encoder click, and inner outter button
extern const int BUTTON_PIN[N_BUTTONS];

// ================================
// MIDI CONFIGURATION
// ================================
// first 5 are for attribute encoders, next 8 are for XKeys encoders
extern const byte ENCODER_NOTES[N_ENCODERS];

// first 5 for encoders, next 8 for XKeys, last one for inner outter flip
extern const byte BUTTON_NOTES[N_BUTTONS];

// Here you can play with the velocity scaling to get the sensitivity you like
// This works well for me with no accel in Pro Plugins Midi Encoders plugin
extern const int VELOCITY_SCALES[8][8];

// Note: Encoder sensitivity variables are now in the config struct (eeprom.h)

//midi channel to send on
extern byte midiCh;

// ================================
// LED CONFIGURATION
// ================================
const int NUM_LOGO_PIXELS = 6;       // Number of pixels in logo section
const int NUM_XKEYS = 16;            // Number of X-keys
const int LEDS_PER_XKEY = 2;         // LEDs per X-key
const int NUM_OFF_LEDS = 18;         // Number of pixels that need to be skiped (both strips need to skip the first and 1 between each key and 2 between the larger gap)
const int TOTAL_PIXELS = (NUM_LOGO_PIXELS + (NUM_XKEYS * LEDS_PER_XKEY) + NUM_OFF_LEDS); // Logo + XKey LEDs + spacer pixels

// LED mapping structure for X-key to pixel index conversion
// Each X-key has a start index for its first LED
// Layout: [6 logo pixels][skip][2 xkey1 LEDs][skip][2 xkey2 LEDs][skip][2 xkey3 LEDs][skip][2 xkey4 LEDs][skip * 2]....
struct XKeyLEDMapping {
  int firstPixelIndex;              // Index of first LED for this X-key
  int secondPixelIndex;             // Index of second LED for this X-key
};

// Default LED mapping - can be manually adjusted if physical layout differs
extern XKeyLEDMapping xkeyLEDMap[NUM_XKEYS];

// Note: Brightness controls are now in the config struct (eeprom.h)

// ================================
// LED UPDATE DEBOUNCE SYSTEM
// ================================
// This prevents LED flashing when multiple MIDI messages arrive in quick succession
extern unsigned long lastMidiUpdateTime;
const unsigned long MIDI_DEBOUNCE_MS = 50; // Wait 50ms after last MIDI message before updating LEDs
extern bool hasPendingLEDUpdate;


// ================================
// PAGE-BASED EXECUTOR STATUS DATA STRUCTURE
// ================================
// Structure to hold executor status information from grandMA3
// Receives data on MIDI channel 2 using optimized CC mapping:
// - Status: XKeys 1-16 use CC 1-16 (combined populated/on state)
// - RGB: XKeys 1-16 use CC 17-64 (3 CCs each, only when populated)
// Page changes received on MIDI channel 3, CC 1 (page number 1-127)
struct ExecutorStatus {
  bool isOn;           // On/off state of executor
  bool isPopulated;    // Whether executor has sequence assigned
  uint8_t red;         // Red  (0-127 MIDI range)
  uint8_t green;       // Green (0-127 MIDI range)
  uint8_t blue;        // Blue (0-127 MIDI range)
};

// Page-based storage for up to 127 pages, 16 XKeys each
// pageData[page][xkey] where page = 0-126 (for pages 1-127), xkey = 0-15 (for XKeys 1-16)
extern ExecutorStatus pageData[127][16];

// Current page tracking (1-127, but stored as 0-126 index)
extern int currentPage;

// Current active status (points to current page data for convenience)
extern ExecutorStatus* xkeyStatus;

// ================================
// ENCODER MANAGEMENT
// ================================
// Array to store current values for encoders 5-12 (absolute mode)
extern int encoderValues[N_ENCODERS];

extern Encoder* encoders[N_ENCODERS];

extern long lastPos[N_ENCODERS];
extern unsigned long lastMoveTime[N_ENCODERS];
extern int buttonPState[N_BUTTONS];
extern bool latchButtonState;
extern unsigned long lastDebounceTime[N_BUTTONS];
extern unsigned long debounceDelay;

extern int encoderBuffer[N_ENCODERS];
extern bool midiDataPending;
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

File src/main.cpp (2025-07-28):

// Written by ShawnR
// Built for Teensy 4.1
// Sends MIDI for Grandma3 Encoders on first 5 CCs of channel 1 using relative velocity for use with Pro Plugins Midi Encoders plugin
// Sends absolute CC values for next 8 encoders for Xkeys 1-8, and recieves MIDI back on same CCs for storing current fader value

// Has one latching button with led status for Flipping from inner to outter encoder function using Pro Plugins Midi Encoders plugin
// Hold the button down and rotate encoder 13 to set brightness for XKeys ON state, rotate encoder 12 for XKeys OFF state brightness
// Use Midi ch1 note 14 for inner outter flip

// Sends notes on encoder click ch1, notes: 1-13
// Encoder click is handled with Midi Remotes created by EvoCmdWingMidi_Main.lua plugin

#include <Arduino.h>
#include <MIDIUSB.h>
#include "config.h"
#include "neopixel.h"
#include "encoders.h"
#include "midi.h"
#include "utils.h"

void setup() {
  Serial.begin(115200);
  if (debugMode) delay(200);

  debugPrint("EvoCmdWing setup");

  initializeEEPROM();
  initializeEncoders();
  initializeLEDs();
  
  xkeyFadeSequenceBounce(50, 1000, 2, 0);  

  setLogoPixels(127, 64, 0, config.logoBrightness); // orange

  debugPrint("Setup complete");
}

void loop() {

  handleIncomingMIDI();
  handleEncoders();
  handleButtons();
  
  if (midiDataPending) {
    usbMIDI.send_now();
    midiDataPending = false;
  }

  // Handle midi often to keep teensy buffer from overflow
  handleIncomingMIDI();
  
  // LED Update all colors at once 
  if (hasPendingLEDUpdate && (millis() - lastMidiUpdateTime) >= MIDI_DEBOUNCE_MS) {
    showStrip();
    hasPendingLEDUpdate = false;
  }
  
  updateXKeyLEDs();
  
  checkSerialForReboot();

}

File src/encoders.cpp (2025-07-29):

#include "encoders.h"
#include "neopixel.h"
#include "utils.h"
#include <MIDIUSB.h>

// ================================
// ENCODER/BUTTON GLOBAL VARIABLES
// ================================

// GPIO pins for encoder a/b
const int ENC_PINS[N_ENCODERS][2] = {
  {0,1}, {2,3}, {4,5}, {6,7}, {8,9}, {11,12}, {14,15},
  {16,17}, {18,19}, {20,21}, {22,23}, {24,25}, {26,27}
};

// GPIO pin for encoder click, and inner outter button
const int BUTTON_PIN[N_BUTTONS] = {
  28,29,30,31,32,33,34,35,36,37,38,39,40,41
};

// first 5 are for attribute encoders, next 8 are for XKeys encoders
const byte ENCODER_NOTES[N_ENCODERS] = {1, 2, 3, 4, 5, 6, 7, 8, 9, 10, 11, 12, 13};

// first 5 for encoders, next 8 for XKeys, last one for inner outter flip
const byte BUTTON_NOTES[N_BUTTONS] = {1,2,3,4,5,6,7,8,9,10,11,12,13,14};

// Here you can play with the velocity scaling to get the sensitivity you like
// This works well for me with no accel in Pro Plugins Midi Encoders plugin
// 10/75 are the max values that ProPlugins will accept
const int VELOCITY_SCALES[8][8] = {
  {1, 1, 1, 1, 1, 1, 2, 2},    // Level 1: Very slow
  {1, 1, 1, 1, 1, 2, 2, 3},    // Level 2: Slow
  {1, 1, 1, 1, 2, 2, 3, 3},    // Level 3: Somewhat slow
  {1, 1, 1, 2, 2, 3, 4, 4},    // Level 4: Slightly slow
  {1, 1, 2, 2, 3, 4, 5, 6},    // Level 5: Current default (good starting point)
  {1, 2, 3, 4, 5, 6, 7, 8},    // Level 6: Slightly fast
  {2, 3, 4, 5, 6, 8, 9, 10},  // Level 7: Fast
  {3, 4, 5, 6, 7, 8, 10, 10} // Level 8: Very fast
};

// Array to store current values for encoders 5-12 (absolute mode)
int encoderValues[N_ENCODERS] = {0}; // Initialize all to 0

// Note: Encoder sensitivity variables moved to config struct in eeprom.h

// Midi channel to send on
byte midiCh = 1;

Encoder* encoders[N_ENCODERS];

long lastPos[N_ENCODERS] = {0};
unsigned long lastMoveTime[N_ENCODERS] = {0};
int buttonPState[N_BUTTONS] = {};
bool latchButtonState = false;
unsigned long lastDebounceTime[N_BUTTONS] = {0};
unsigned long debounceDelay = 50;  // debounce for encoder buttons

int encoderBuffer[N_ENCODERS] = {0};
bool midiDataPending = false;


// Adjustment mode (brightness & sensitivity)
bool adjustMode = false;                  // True when button 14 is held down for brightness/sensitivity adjustment
bool sensitivityMode = false;             // True when actively adjusting sensitivity (blocks normal LED updates)
unsigned long encoderFlipHoldTime = 0;       // Time when button 14 was pressed

const int ENCODER_FLIP_HOLD_DURATION = 500;   // Time is ms to determin a hold and not a press

// ================================
// ENCODER AND BUTTON FUNCTIONS
// ================================

void initializeEncoders() {
  for (int i = 0; i < N_ENCODERS; i++) {
    encoders[i] = new Encoder(ENC_PINS[i][0], ENC_PINS[i][1]);
    lastPos[i] = encoders[i]->read();

    if (i >= 5) {
      encoderValues[i] = 0;
    }
  }
  for (int i = 0; i < N_BUTTONS; i++) {
    pinMode(BUTTON_PIN[i], INPUT_PULLUP);
  }
  
  pinMode(LATCH_LED_PIN, OUTPUT);
  digitalWrite(LATCH_LED_PIN, LOW);
}

// Handles encoder moves (every 4 in the same direction) and sends midi output
void handleEncoders() {
// Buffer the encoder reads to keep from getting bouncing or jumpy readings
  for (int i = 0; i < N_ENCODERS; i++) {
    long movement = encoders[i]->readAndReset();
    encoderBuffer[i] += movement;

    while (abs(encoderBuffer[i]) >= 4) {
      int dir = (encoderBuffer[i] > 0) ? 1 : -1;
      sendMidiEncoder(i, dir);
      encoderBuffer[i] -= (4 * dir);
    }

  }
}
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

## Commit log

2025-06-16 added midi button presses to lua, and help files, and gma3 plugin folder structure
2025-06-16 changed repo name
    [Base.stl, Keyplate.stl, Top.stl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]
2025-06-17 add image
    [stand_tilted.stl]
2025-06-17 Fixed keyplate keyswitch locking
    [gma3cmdwingV1.f3d]
2025-06-17 modified keyplate stl
    [Keyplate.stl]
2025-07-23 Update to v0.2
    [Base.stl, Blank D-type.stl, Keyplate.stl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]
2025-07-23 added image
    [70X30mm_board_mount.stl, D-type_DC_barrel_plate.stl, teensy4.0_breakout_mount.stl]
2025-07-24 Update EvoCmdWingv0.2_keyboard_shortcuts.xml
    Removed ESC shortcut, it is now handled natively.
2025-07-28 added logo led brightness change using encoder index 10
2025-07-28 added 8 lvl encoder sens adjustment, button14 + encoder 5 and 6
2025-09-14 updated python multi upload script, for uploading to specific teensy without bootloader button
2025-09-14 updated solo button shortcut from alt+e to alt+g for use on macos
